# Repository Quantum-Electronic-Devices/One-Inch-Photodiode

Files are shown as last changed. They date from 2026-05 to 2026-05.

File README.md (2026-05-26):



# 1″-Photodetector
This repository contains the [KiCad](https://www.kicad.org/) schematics and design files for the [QED 1″-Photodetector](https://quantum-electronic-devices.de/en/products/electronics/1-photodetector/).

<p align="center">
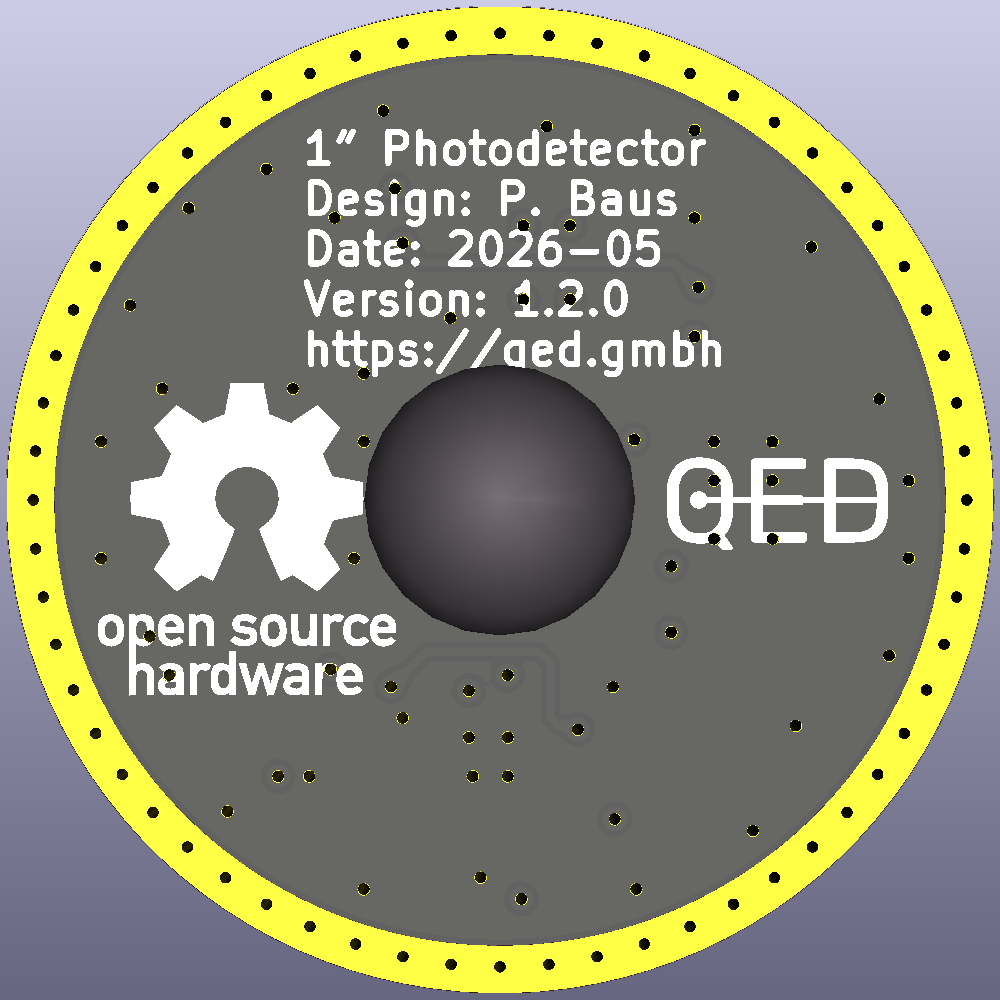
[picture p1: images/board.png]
  
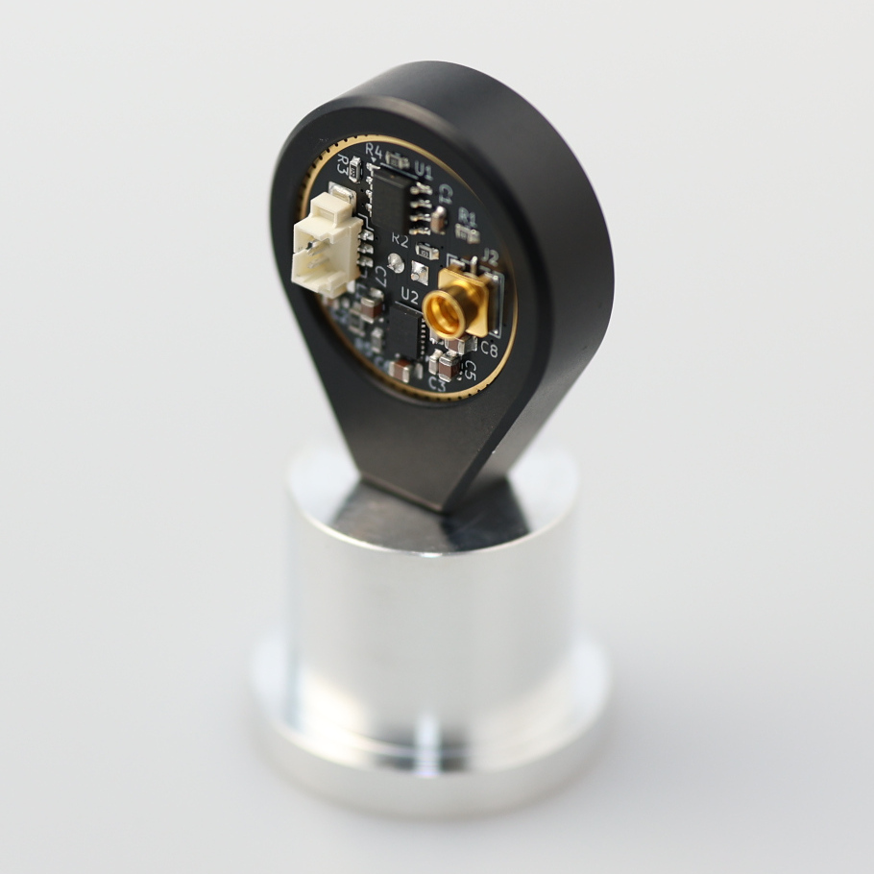
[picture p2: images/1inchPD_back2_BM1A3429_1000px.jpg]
  
</p>

## Contents
- [Introduction](#introduction)
- [Datasheet](#datasheet)
- [Design Files](#design-files)
- [Versioning](#versioning)
- [License](#license)

## Introduction
The [QED 1″-Photodetector](https://quantum-electronic-devices.de/en/products/electronics/1-photodetector/) is a circular shaped photodetector with an outer diameter of 25.4 mm and an [Osram SFH 203 photodiode](https://ams-osram.com/products/photodetectors/photodiodes/osram-radial-t1-34-sfh-203) mounted in the centre. It can be easily integrated into 1″ cage systems, such as Thorlabs' 30 mm cage mounts (e.g. the [CP33/M](https://www.thorlabs.com/item/CP33_M)). This makes the photodetector ideal for reliable and sturdy setups that can be quickly assembled for tasks such as laser power monitoring or intensity stabilisation. It has a [TIA](https://en.wikipedia.org/wiki/Transimpedance_amplifier) gain of 10 kV/A and an additional voltage gain of 5. The bandwidth is 8 MHz. The full specifications can be found in the [datasheet](#datasheet).

## Datasheet
The datasheet is available with every release and it lists the most important electrical and mechanical specifications. The latest version can be found [here](../../releases/latest/download/datasheet.pdf). Older versions can be found attached to the respective [release](../../releases).

## Design Files
### For production
The design files required for the PCB production and assembly can be found on the [releases](../../releases) page and include the following resources:

- Schematics as a PDF
- Gerber files
- Pick & place position files
- Bill of materials as a CSV file, as well as an interactive HTML version

The latest revision of those files can be found [here](../../releases/latest).

### For editing
To work on the [KiCad](https://www.kicad.org/) design files, a number of external libraries are needed. Those libraries show up as empty folders in the zip file, because they are not included in the release, but must be downloaded separately from the links given [below](#related-repositories). This can be avoided by checking out the whole repository using git. This way the libraries will be downloaded as well. Use the following command to clone the git repository along with the submodules  using the `--recurse-submodules` flag.
```
git clone --recurse-submodules https://github.com/Quantum-Electronic-Devices/One-Inch-Photodiode.git
```

## Versioning
We use [SemVer](http://semver.org/) for versioning. For the available versions, see the repository's [tags](../../tags).

- MAJOR versions in this context mean a breaking change to the external interface of the hardware like different connectors or functions.
- MINOR versions contain changes to the hardware that only affect the inner workings of the circuit, but otherwise the performance is unaffected.
- PATCH versions do not affect the schematics or invalidate older bill of materials. These changes may include updated components (to replace obsolete parts for example), an updated silkscreen, or fixed typos.

## License
This work is released under the CERN-OHL-W
See [https://ohwr.org/cern_ohl_w_v2.pdf](https://ohwr.org/cern_ohl_w_v2.pdf) or the included LICENSE file for more information.

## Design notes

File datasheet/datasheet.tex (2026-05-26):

%\DocumentMetadata{%
%pdfstandard=A-3b,%
%lang=en,
%}
\documentclass[fontsize=10pt]{datasheet}

% Input encoding and typographical rules for English language
\usepackage{iftex}
\ifPDFTeX
    \usepackage[utf8]{inputenc}
\else
    \ifXeTeX
        \usepackage{fontspec}
    \fi
\fi

\usepackage[english]{babel}
\usepackage[iso,english]{isodate}
\usepackage{siunitx}
\usepackage[subpreambles=true]{standalone}
\usepackage{import}

% hyperref was loaded by the template
\hypersetup{pdftitle=One-Inch-Photodetector datasheet,pdfauthor=Patrick Baus}

\usepackage{graphicx}
\usepackage{qrcode}
% xcolor needs to be loaded before tikz to ensure the use of RGB colors instead of natural colors
\usepackage[rgb]{xcolor}
\usepackage{tikz}

\DeclareSIUnit{\year}{a}
\DeclareSIUnit{\HP}{HP}
\DeclareSIUnit{\inch}{''}
\DeclareSIUnit{\U}{U}
\DeclareSIUnit{\rH}{\%rH}
\sisetup{%
    separate-uncertainty = true,% display the uncertainty as 10 \pm 2
    input-digits = 0123456789\pi,%
    power-half-as-sqrt,%
    per-mode=symbol,%
    range-phrase=\textup{~to~},%
    text-family-to-math = true,%
    text-series-to-math = true,%
    propagate-math-font = true,%
    reset-math-version = false
}

% Change the toc title
\addto\captionsenglish{% Replace "english" with the language you use
  \renewcommand{\contentsname}%
    {Table of Contents}%
}

\DeclareTOCStyleEntry[
  linefill=\TOCLineLeaderFill
]{tocline}{section}

% These define global texts that are used in headers and titles.
\title{\qty{1}{in}-Photodetector}
\author{Patrick Baus, QED}
\date{\today}
\newcommand{\versionNumber}{0.1.2}
\revision{Revision \versionNumber}
\newcommand{\repoUrl}{https://github.com/Quantum-Electronic-Devices/One-Inch-Photodiode}
\companylogo{%
  \begin{tikzpicture}[remember picture,overlay]
    \path (current page.north west) node[below right,fill=black,minimum
width=\paperwidth,minimum height=3cm] (box){};%
    \path (box.west) node[right=10mm,align=left]{};%
  \end{tikzpicture}
}

\newcounter{tableNoteCounter}
\newcommand{\note}[1]{\refstepcounter{tableNoteCounter}\textbf{Note thetableNoteCounter\label{note:#1}}}

\captionsetup{
  justification=raggedright,
  singlelinecheck=false
}

\begin{document}
\maketitle

\section*{Features}

\begin{itemize}
\item{Small \qty{1}{inch} form factor fits \qty{30}{\mm} cage systems}
\item{VIS and NIR options}
\item{Supply voltage: \qtyrange{12}{18}{\V}}
\item{Bandwidth: \qty{8}{\MHz}}
\item{Sensitivity: \qty{31}{\V \per \mW}}
\item{Input referred noise: \qty{<3}{\pA \per \Hz\tothe{0.5}}}
\item{Transimpedance: \qty{50}{\V \per \mA}}
\item{Fully open-source design}
\end{itemize}

\section*{Applications}

\begin{itemize}
\item{Intensity stabilisation}
\item{Monitoring applications}
\end{itemize}

\section*{General Description}
The \qty{1}{\inch}-Photodetector is a low-noise, free-space photodetector with an 8 MHz bandwidth and a rise time of 42 ns. Standard versions available are: VIS-NIR (\href{https://ams-osram.com/products/photodetectors/photodiodes/osram-radial-t1-34-sfh-203}{Osram SFH 203}) and NIR (\href{https://ams-osram.com/products/photodetectors/photodiodes/osram-radial-t1-34-sfh-203-fa}{Osram SFH 203 FA}), which blocks blocks ambient visible light up to \qty{750}{\nm}. These cover the spectral range from \qtyrange{400}{1100}{\nm} (SFH 203, \qty{10}{\percent} sensitivity) or \qtyrange{750}{1100}{\nm}  (SFH 203 FA, \qty{10}{\percent} sensitivity). The \qty{1}{\inch}-Photodetector demonstrates exceptional performance in applications such as optical power control loops and power monitoring, with a noise floor of \qty{<3}{\pA \per \Hz\tothe{0.5}} and a sensitivity of \qty{31}{\V \per \mW}.

It is designed to be easily mounted in a 30 mm cage system using a standard ⌀ \qty{1}{\inch} cage plate. With a sensitivity of \qty{31}{\V \per \mW}, it requires only micro watts to deliver a reliable and stable signal. In a typical application such as an optical power control loop, a \qty{45}{\degree} beamsampler within the cage system directs a small fraction of the laser beam onto the detector. This allows, for example, a beam coupled out of a fibre to be monitored for further experiments on the optical table. Integrating the photodetector into the cage system guarantees superior stability compared to solutions mounted on separate posts.

\begin{figure}[ht]
    \centering
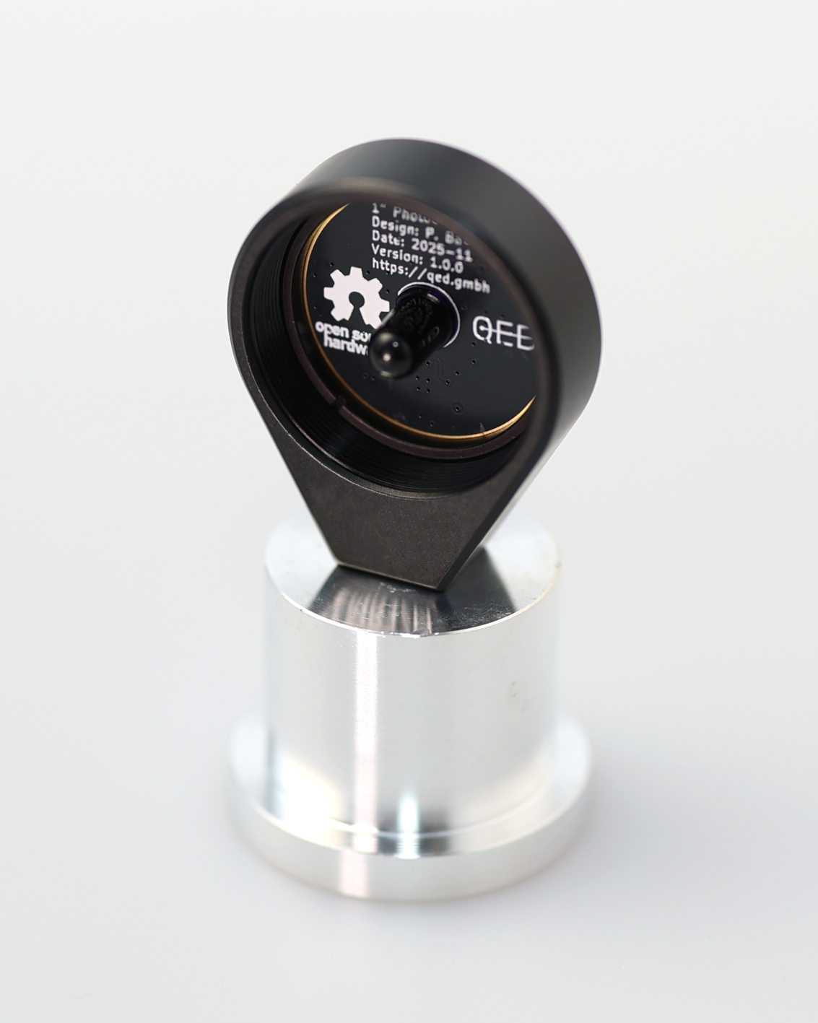
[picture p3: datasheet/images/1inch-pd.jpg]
    
\end{figure}

Using a small footprint SMP connector the photodetecor can also be mounted in space constrained applications. The plug-and-play SMP connector ensures that the connector is always seated properly, eliminating noise caused by poor contacts.

% Switch to next column
\vfill\break

\tableofcontents

% For wide tables, a single column layout is better. It can be switched
% page-by-page.
\onecolumn

\section{Revision History}
\begin{table}[h]
    \centering
    \begin{tabularx}{\textwidth}{l| l | >{\raggedright\arraybackslash}X}
        \thickhline
        Version& Date& Comment\\
        \hline
        0.1.0 &2026-05-22 &Initial release. Compatible with hardware revision 1.0.0.\\
        \hline
        0.1.1 &2026-05-22 &Fixed QR-Code URL.\\
        \hline
        \versionNumber &2026-05-26 &Updated datasheet style to KOMA fixing page numbering.\\
        \thickhline
    \end{tabularx}
\end{table}

The latest release of this document can be found at \url{\repoUrl} or use the QR-code below.

\begin{center}
    \qrcode[nolinks]{\repoUrl}
\end{center}
\end{document}

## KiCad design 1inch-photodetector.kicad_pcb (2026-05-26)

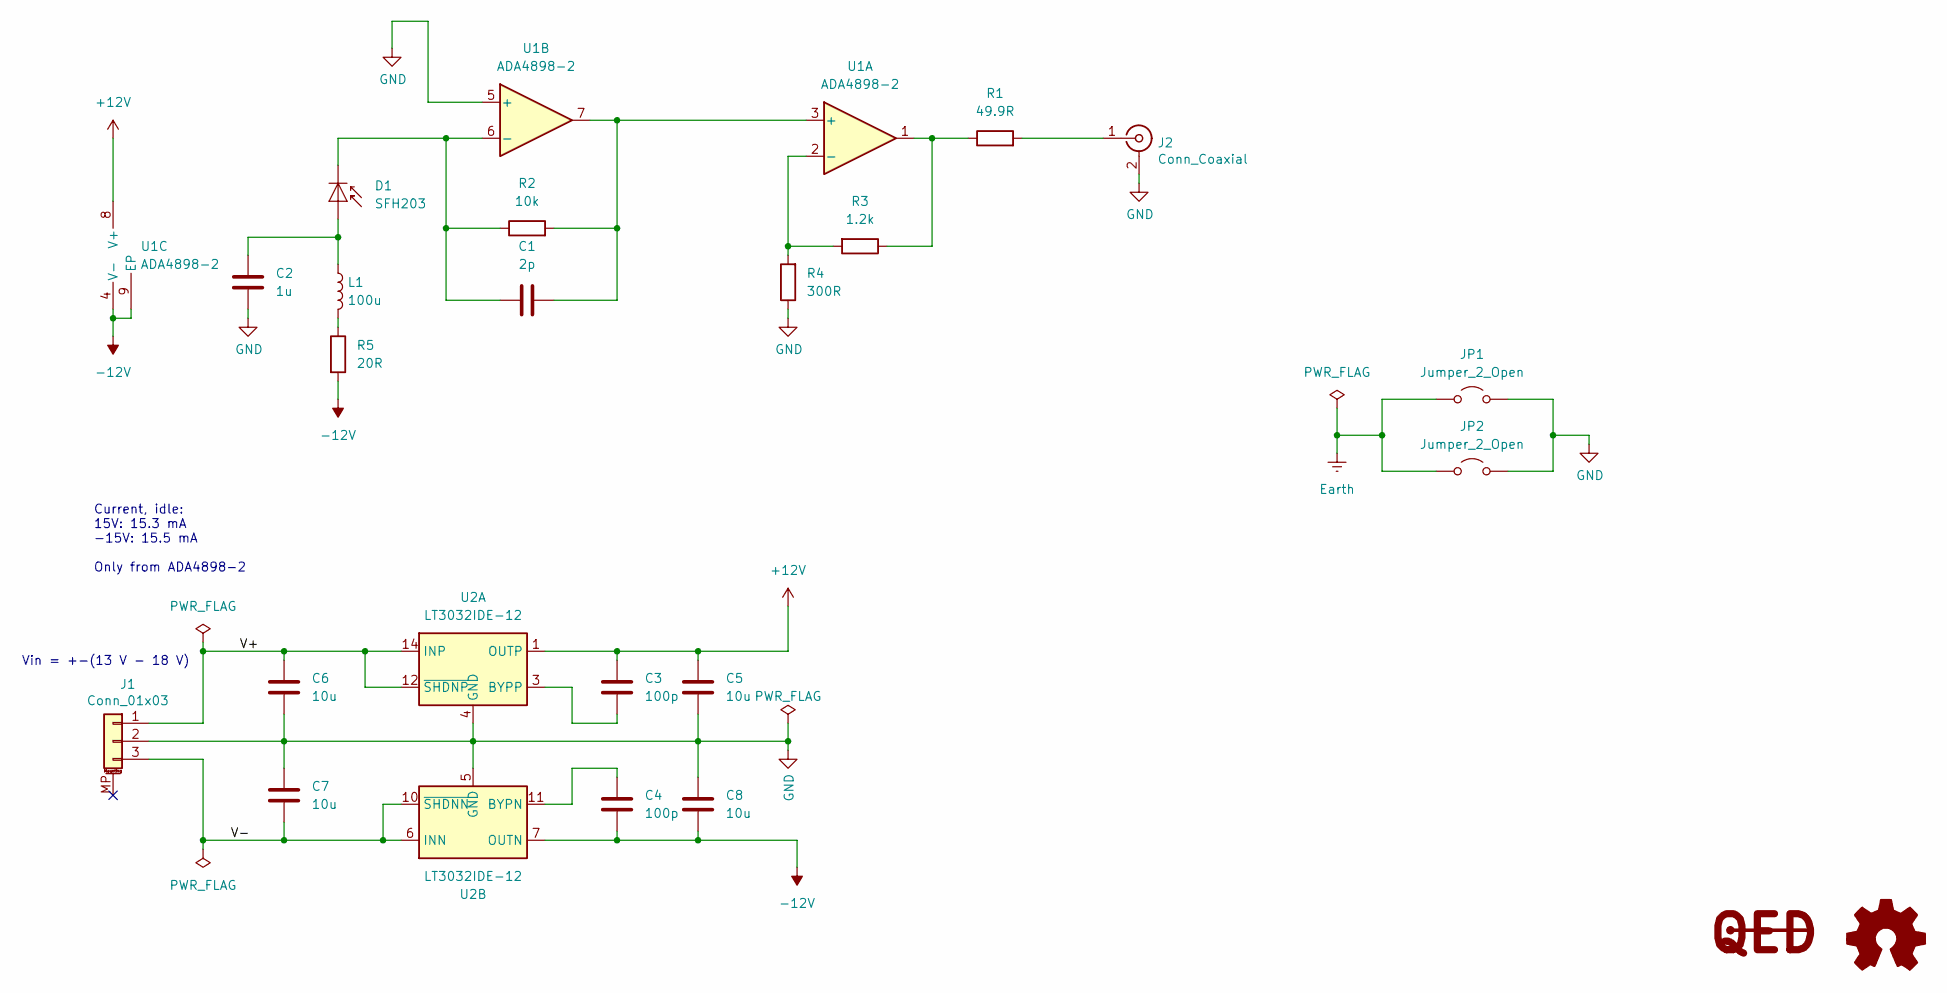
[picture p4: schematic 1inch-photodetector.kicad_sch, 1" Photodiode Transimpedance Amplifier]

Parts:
C1: 2p; C_0603_1608Metric
C2: 1u; C_0603_1608Metric
C3, C4: 100p; C_0603_1608Metric
C5, C6, C7, C8: 10u; C_0805_2012Metric
D1: SFH203; LED_D5.0mm_IRGrey
J1: Conn_01x03; Molex_PicoBlade_53398-0371_1x03-1MP_P1.25mm_Vertical
J2: Conn_Coaxial; SMP_TE_CONSMP001-SMD-G-T_Vertical
JP1, JP2: Jumper_2_Open; R_0402_1005Metric
L1: 100u; L_0805_2012Metric
LOGO1: Logo_Open_Hardware_Large; OSHW-Logo_7.5x8mm_SilkScreen
R1: 49.9R; R_1206_3216Metric
R2: 10k; R_0603_1608Metric
R3: 1.2k; R_0603_1608Metric
R4: 300R; R_0603_1608Metric
R5: 20R; R_0603_1608Metric
SYM1: Logo_QED; QED-logo_small
U1: ADA4898-2; SOIC-8-1EP_3.9x4.9mm_P1.27mm_EP2.41x3.81mm
U2: LT3032IDE-12; Linear_DE14MA

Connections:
+12V: C3.1, C5.1, U1.8 (V+), U2.1 (OUTP)
-12V: C4.2, C8.2, R5.2, U1.4 (V-), U1.9 (EP), U2.7 (OUTN)
/V+: C6.1, J1.1, U2.12 (~SHDNP), U2.14 (INP)
/V-: C7.2, J1.3, U2.6 (INN), U2.9 (INN), U2.10 (~SHDNN)
Earth: JP1.1 (A), JP2.1 (A)
GND: C2.2, C5.2, C6.2, C7.1, C8.1, J1.2, J2.2 (Ext), JP1.2 (B), JP2.2 (B), R4.1, U1.5 (+), U2.4 (GND), U2.5 (GND)
unnamed: C2.1, D1.2 (A), L1.1
unnamed: C1.1, D1.1 (K), R2.1, U1.6 (-)
unnamed: J2.1 (In), R1.2
unnamed: L1.2, R5.1
unnamed: R1.1, R3.1, U1.1
unnamed: C1.2, R2.2, U1.3 (+), U1.7
unnamed: R3.2, R4.2, U1.2 (-)
unnamed: C3.2, U2.3 (BYPP)
unnamed: C4.1, U2.11 (BYPN)

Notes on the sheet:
Vin = +-(13 V - 18 V)
Current, idle: 15V: 15.3 mA -15V: 15.5 mA Only from ADA4898-2

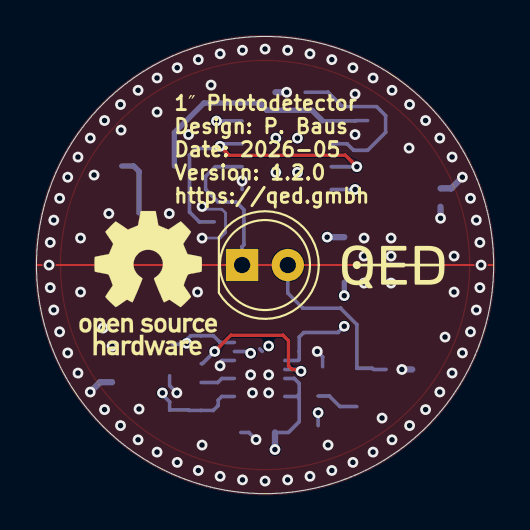
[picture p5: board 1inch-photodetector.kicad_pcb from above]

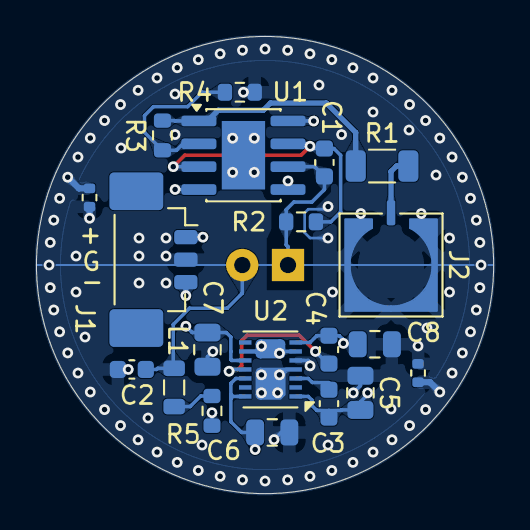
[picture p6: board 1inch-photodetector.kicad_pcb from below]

Board: 4 copper layers, 25.4 x 25.4 mm, 23 parts (20 on the bottom side), 15 nets.

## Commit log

2026-03-01 Add 'Do not touch artwork' disclaimer (#15)
    - Added more disclaimers for assembly
    [1inch-photodetector.kicad_pcb]
2026-03-02 Update CI to reusable workflow (#17)
    * Update CI to reusable workflow
    * Fixed PCB<->SCH mismatch
    [1inch-photodetector.kicad_pcb]
2026-03-02 Added teardrops (#22)
    * Added teardrops
    * Refilled board
    [1inch-photodetector.kicad_pcb]
2026-03-02 Refactor/footprints (#24)
    * Set artifact retention to 7 days
    * Renamed custom footprint lib
    * Bump QED logo to latest
    * Bump GitHub actions
    [1inch-photodetector.kicad_pcb, 1inch-photodetector.kicad_sch]
2026-05-26 Fix missing soldermask cutout at the edges (#28)
    * Fix missing soldermask cutout around PD
    - Bump KiCad to version 10
    * Bump CI
    [1inch-photodetector.kicad_pcb, 1inch-photodetector.kicad_sch]

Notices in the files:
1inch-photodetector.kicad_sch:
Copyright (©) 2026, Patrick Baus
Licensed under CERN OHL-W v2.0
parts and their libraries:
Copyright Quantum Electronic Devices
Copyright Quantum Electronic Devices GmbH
